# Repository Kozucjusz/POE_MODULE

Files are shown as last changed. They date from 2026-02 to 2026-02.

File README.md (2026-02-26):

## 1. Introduction
A 100-W Power over Ethernet (PoE) module for device power supply and Ethernet data transmission.
## 2. Key Components:
- 7499511420 WÜRTH - PoE++ Ethernet connector with an integrated transformer, rated for 100 W power.
- PSM040-100MSE - MOSFETs forming active ideal bridge rectifier circuits.
- LT4321 - dual ideal bridge controller for PoE applications.
- LT4320 - single ideal bridge controller, used for the auxiliary power section.
- LT4275 - PoE controller.

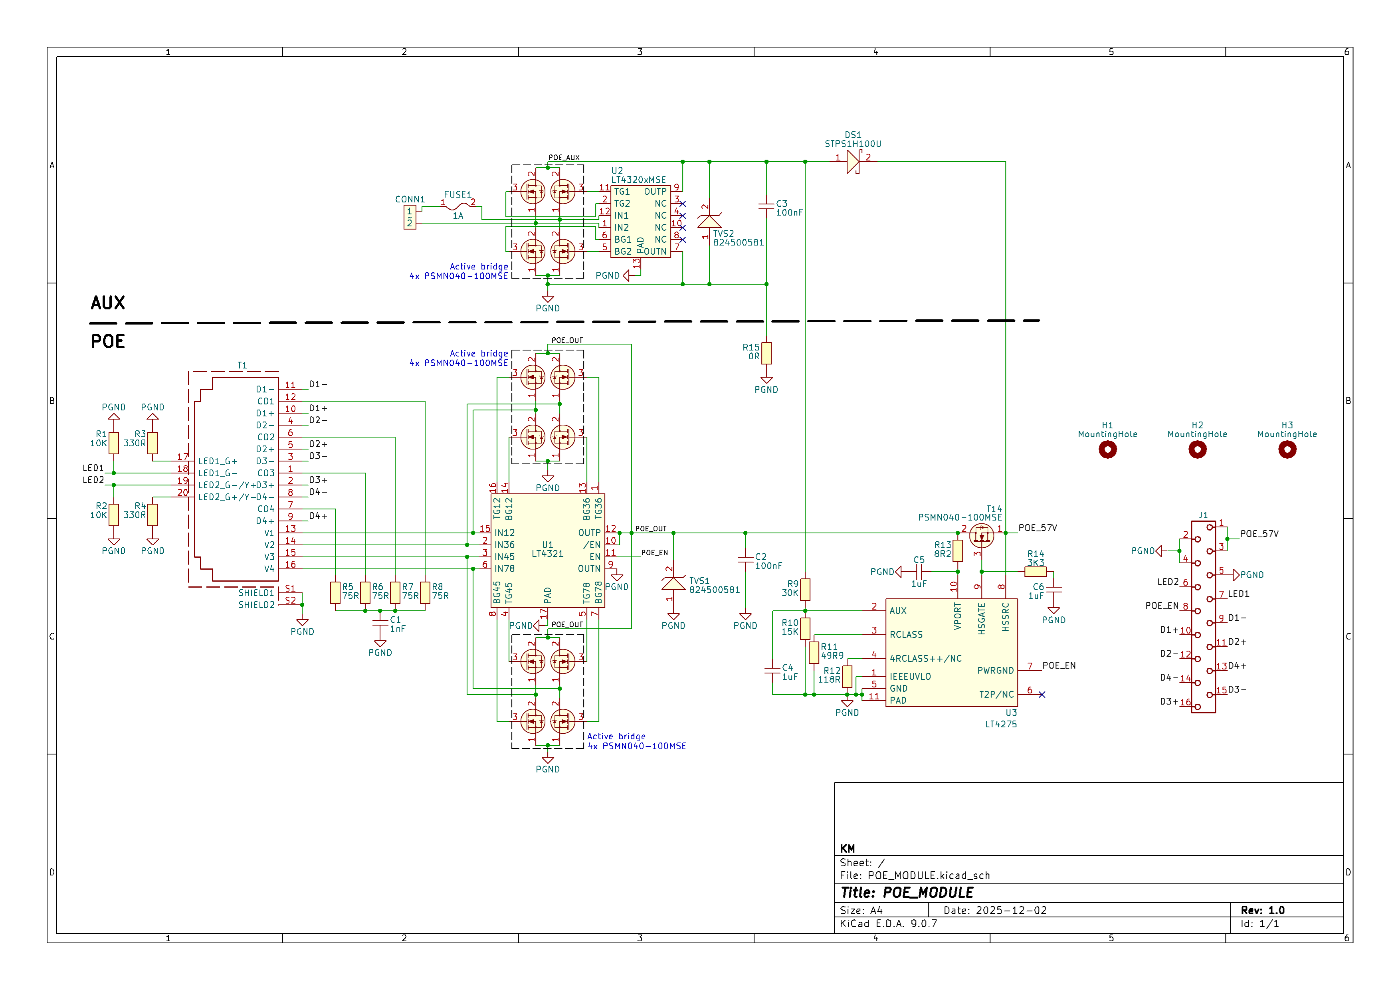
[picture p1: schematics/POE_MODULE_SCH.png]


## 3. PCB
The designed PCB is divided into two independent functional blocks: PoE and AUX.
The PoE section provides the primary power supply compliant with the Power over Ethernet standard, while the AUX section serves as an alternative, redundant power source intended for operation in the absence of power from the PSE device or in the event of a PoE path failure.

The AUX section allows the module to be powered either from an external DC voltage source or from mains voltage after prior step-down conversion. This solution increases application flexibility and enables the module to be used in systems requiring high power-supply reliability. In cases of space constraints, the AUX section can be mechanically separated—the corresponding part of the PCB may be broken off before component assembly without affecting the correct operation of the PoE section.

The output power of the module can be configured by selecting appropriate resistor values connected to the RCLASS and 4RCLASS++ pins of the LT4275 controller. This allows easy adjustment of the power class to meet specific application requirements without modifying the rest of the design.

To improve energy efficiency and reduce power losses, active bridge rectifiers were used. This approach enables higher output power while significantly reducing thermal losses compared to conventional diode bridges, which is particularly important in ~100 W applications with limited heat dissipation capability.

The use of widened power traces and connection of three connector pins for each power rail ensures safe and stable current flow of up to 1 A without excessive voltage drops or local trace overheating.
Ethernet signal traces were designed with controlled impedance in accordance with differential transmission requirements. Trace widths and spacing between differential pairs were selected to ensure proper characteristic impedance, minimizing signal reflections and preserving signal integrity.

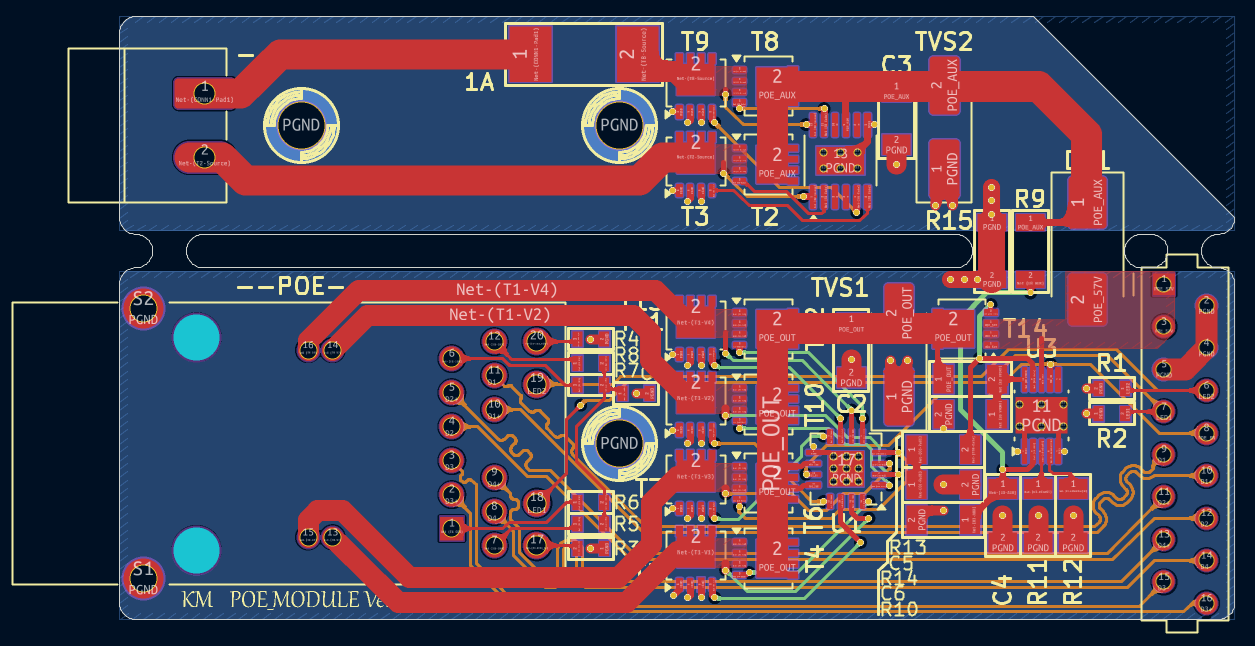
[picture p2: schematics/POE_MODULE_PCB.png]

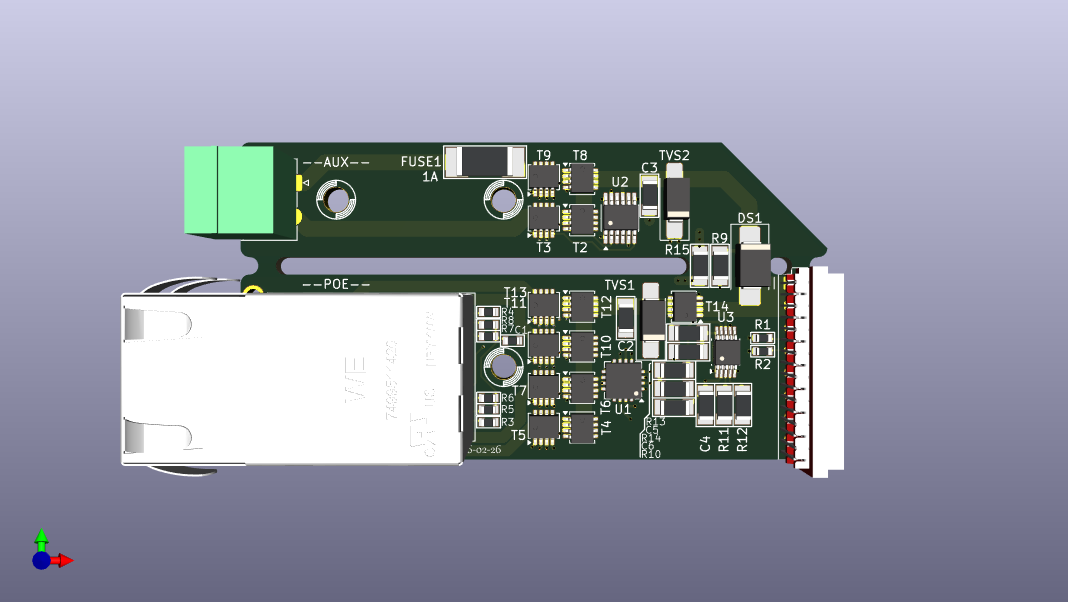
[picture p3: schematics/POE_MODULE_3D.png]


## 4. TEST
Due to the high cost of components required to support the full 100 W power level, the current version of the module has been configured for a maximum output power of 25 W. This allowed verification of the power-supply architecture, the PoE power path, and the overall design assumptions while keeping prototyping costs under control.
For testing purposes, an Ethernet connector compliant with PoE Type 2 was used, enabling safe functional testing and validation of system behavior under conditions corresponding to a lower power class. Configuration of the PoE controller operating parameters is achieved by adjusting the values of the configuration resistors.

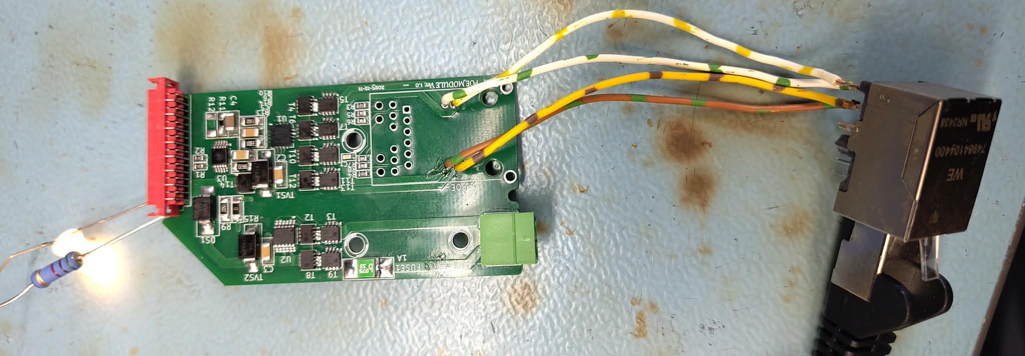
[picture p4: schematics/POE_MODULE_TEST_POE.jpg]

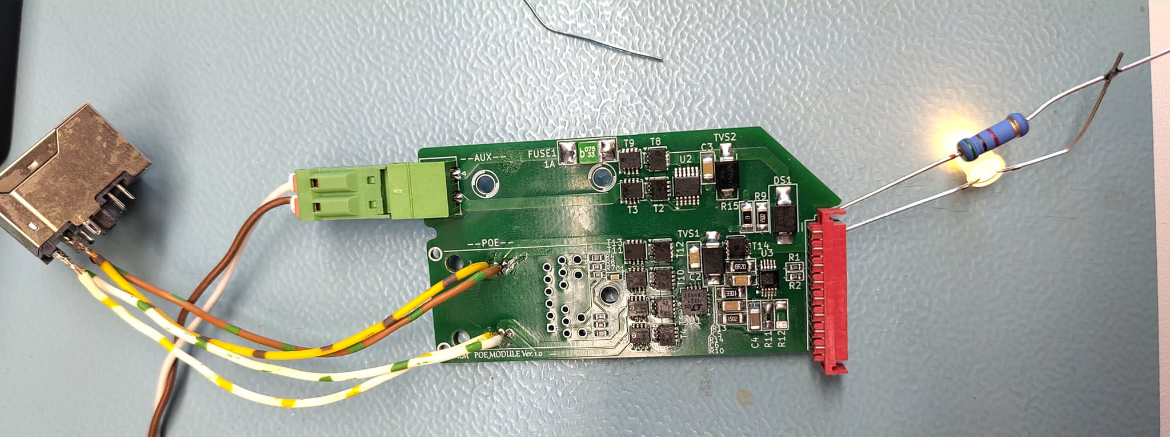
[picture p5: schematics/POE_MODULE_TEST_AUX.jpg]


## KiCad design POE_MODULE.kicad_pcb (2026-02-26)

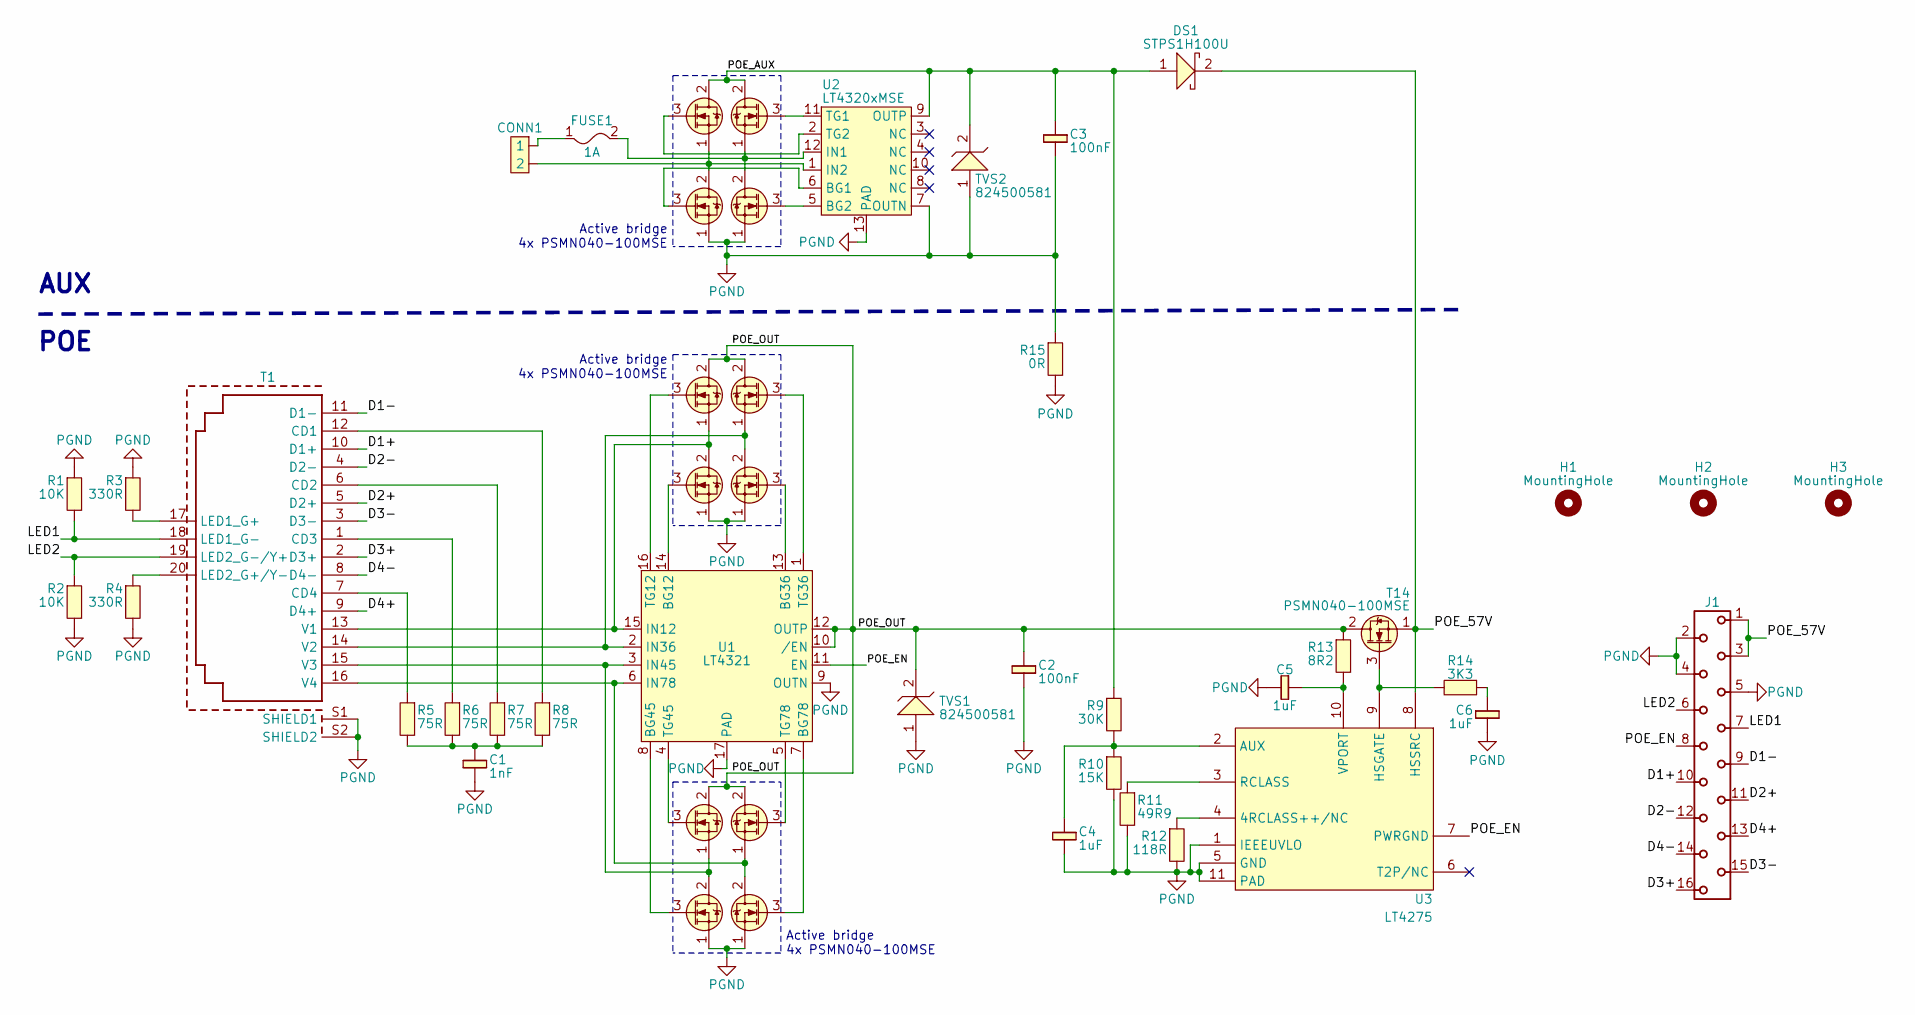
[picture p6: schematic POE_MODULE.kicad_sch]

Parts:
C1: 1nF; RLC_0603_1608Metric
C2, C3: 100nF; RLC_1206_3216Metric
C4, C5, C6: 1uF; RLC_1206_3216Metric
CONN1: PhoenixContact_MC_1,5_2-G-3.81_1x02_P3.81mm_Horizontal
DS1: STPS1H100U; D_SMB_Handsoldering
FUSE1: 1A; RLC_2512_6432Metric
H1, H2, H3: MountingHole; MOUNT_HOLE
J1: 690368171672; J_Wurth_WR-MM_690368171672; Working Voltage (V (AC)) 250
R1, R2: 10K; RLC_0603_1608Metric
R3, R4: 330R; RLC_0603_1608Metric
R5, R6, R7, R8: 75R; RLC_0603_1608Metric
R9: 30K; RLC_1206_3216Metric
R10: 15K; RLC_1206_3216Metric
R11: 49R9; RLC_1206_3216Metric
R12: 118R; RLC_1206_3216Metric
R13: 8R2; RLC_1206_3216Metric
R14: 3K3; RLC_1206_3216Metric
R15: 0R; RLC_1206_3216Metric
T1: 7499511420; T_Wurth_WE-RJ45LAN_7499511420; Part Number 7499511420
T2, T3, T4, T5, T6, T7, T8, T9, T10, T11, T12, T13, T14: PSMN040-100MSE; LFPAK33
TVS1, TVS2: 824500581; D_SMA_Handsoldering
U1: LT4321; QFN-16-1EP_4x4mm_P0.65mm_EP2.1x2.1mm_ThermalVias
U2: LT4320xMSE; MSOP-12-1EP_3x4.039mm_P0.65mm_EP1.651x2.845mm_ThermalVias
U3: LT4275; MSOP-10-1EP_3x3mm_P0.5mm_EP2.2x3.1mm_Mask1.83x1.89mm_Therma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

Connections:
/D1+: J1.10, T1.10 (D1+)
/D1-: J1.9, T1.11 (D1-)
/D2+: J1.11, T1.5 (D2+)
/D2-: J1.12, T1.4 (D2-)
/D3+: J1.16, T1.2 (D3+)
/D3-: J1.15, T1.3 (D3-)
/D4+: J1.13, T1.9 (D4+)
/D4-: J1.14, T1.8 (D4-)
/LED1: J1.7, R1.2, T1.18 (LED1_G-)
/LED2: J1.6, R2.1, T1.19 (LED2_G-/Y+)
/POE_57V: DS1.2, J1.1, J1.3, T14.1 (Source), U3.8 (HSSRC)
/POE_AUX: C3.1, DS1.1, R9.1, T2.2 (Drain), T8.2 (Drain), TVS2.2, U2.9 (OUTP)
/POE_EN: J1.8, U1.11 (EN), U3.7 (PWRGND)
/POE_OUT: C2.1, R13.1, T4.2 (Drain), T6.2 (Drain), T10.2 (Drain), T12.2 (Drain), T14.2 (Drain), TVS1.2, U1.10 (/EN), U1.12 (OUTP)
unnamed: C1.1, R5.2, R6.2, R7.2, R8.2
unnamed: C6.1, R14.1
unnamed: CONN1.1, FUSE1.1
unnamed: R8.1, T1.12 (CD1)
unnamed: R7.1, T1.6 (CD2)
unnamed: R6.1, T1.1 (CD3)
unnamed: R5.1, T1.7 (CD4)
unnamed: R3.2, T1.17 (LED1_G+)
unnamed: R4.1, T1.20 (LED2_G+/Y-)
unnamed: T1.13 (V1), T4.1 (Source), T5.2 (Drain), U1.15 (IN12)
unnamed: T1.14 (V2), T10.1 (Source), T11.2 (Drain), U1.2 (IN36)
unnamed: T1.15 (V3), T6.1 (Source), T7.2 (Drain), U1.3 (IN45)
unnamed: T1.16 (V4), T12.1 (Source), T13.2 (Drain), U1.6 (IN78)
unnamed: T2.3 (Gate), U2.2 (TG2)
unnamed: CONN1.2, T2.1 (Source), T3.2 (Drain), U2.1 (IN2)
unnamed: T3.3 (Gate), U2.6 (BG1)
unnamed: T4.3 (Gate), U1.16 (TG12)
unnamed: T5.3 (Gate), U1.14 (BG12)
unnamed: T6.3 (Gate), U1.4 (TG45)
unnamed: T7.3 (Gate), U1.8 (BG45)
unnamed: T8.3 (Gate), U2.11 (TG1)
unnamed: FUSE1.2, T8.1 (Source), T9.2 (Drain), U2.12 (IN1)
unnamed: T9.3 (Gate), U2.5 (BG2)
unnamed: T10.3 (Gate), U1.1 (TG36)
unnamed: T11.3 (Gate), U1.13 (BG36)
unnamed: T12.3 (Gate), U1.5 (TG78)
unnamed: T13.3 (Gate), U1.7 (BG78)
unnamed: R14.2, T14.3 (Gate), U3.9 (HSGATE)
unnamed: R12.1, U3.4 (4RCLASS++/NC)
unnamed: C4.1, R9.2, R10.1, U3.2 (AUX)
unnamed: R11.1, U3.3 (RCLASS)
unnamed: C5.1, R13.2, U3.10 (VPORT)
PGND: C1.2, C2.2, C3.2, C4.2, C5.2, C6.2, J1.2, J1.4, J1.5, R1.1, R2.2, R3.1, R4.2, R10.2, R11.2, R12.2, R15.1, R15.2, T1.S1 (SHIELD1), T1.S2 (SHIELD2), T3.1 (Source), T5.1 (Source), T7.1 (Source), T9.1 (Source), T11.1 (Source), T13.1 (Source), TVS1.1, TVS2.1, U1.9 (OUTN), U1.17 (PAD), U2.7 (OUTN), U2.13 (PAD), U3.1 (IEEEUVLO), U3.5 (GND), U3.11 (PAD)

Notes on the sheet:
AUX POE
Active bridge 4x PSMN040-100MSE

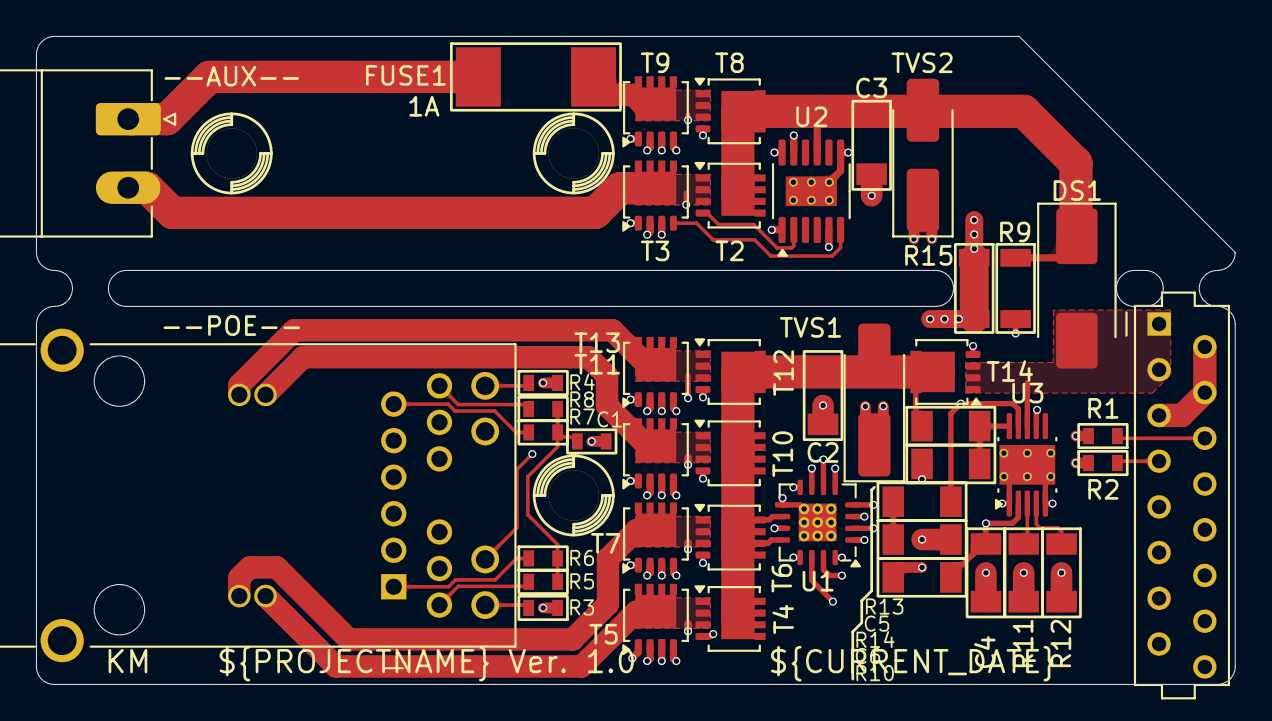
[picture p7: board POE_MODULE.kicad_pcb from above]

Board: 4 copper layers, 66.6 x 36.0 mm, 47 parts (0 on the bottom side), 47 nets.
